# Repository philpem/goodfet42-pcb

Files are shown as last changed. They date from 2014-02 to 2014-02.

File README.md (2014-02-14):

GoodFET42 Modified PCB

This is a modified version of Travis Goodspeed's "GoodFET42" JTAG pod design.
The schematic has not been modified (except for renaming "LED1" to "MO" to
indicate its role as the Mode LED), but the PCB has been modified to allow it to
be built by hobbyists with a relatively modest home PCB lab.

Design rules are thus:

  * Top and bottom sides are linked by large vias, well away from ICs. This
    allows the top and bottom sides to be linked with Harwin track pins, pieces
    of solid-core wire, or similar things.
  * Tracks may enter SMD pads from the short side only, perpendicular with the
    long side (in other words: "make the pad longer"). This makes it easier to
    determine whether a short between two IC pins is intentional.
  * IDC connector is soldered on the bottom side only; tracks may connect from
    the bottom layer only. Most home PCB labs don't have through-plating
    facilities :)
  * 16 mil isolation from ground plane to tracks and pads.

Enjoy!

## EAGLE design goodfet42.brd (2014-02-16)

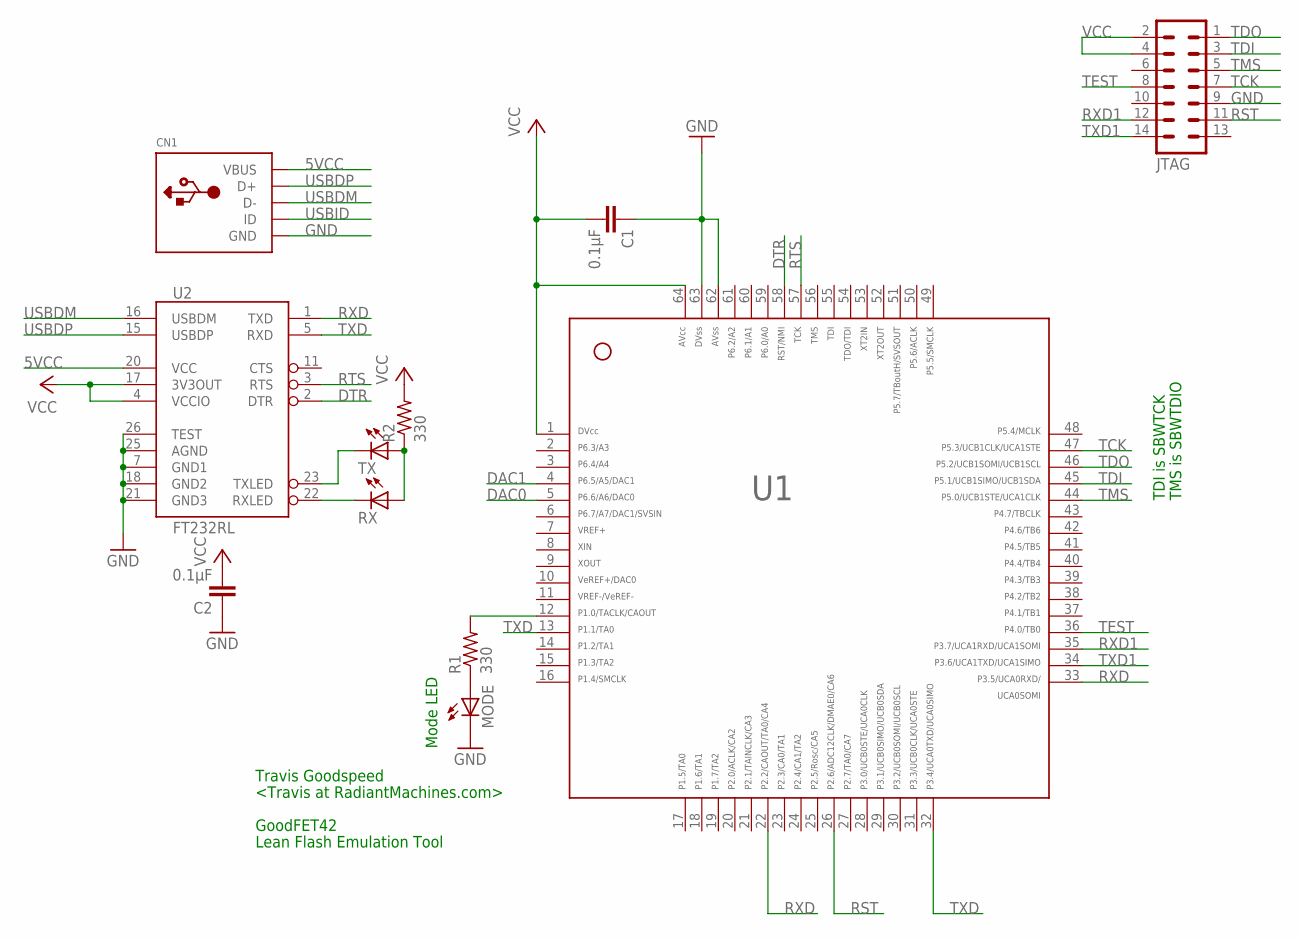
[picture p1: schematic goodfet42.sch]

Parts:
C1, C2: 0.1µF; C0603
CN1: USBMINIB; USB-MINIB
JTAG: MA07-2
MODE: LEDCHIP-LED0603; CHIP-LED0603
R1, R2: 330; R0603
RX: LEDCHIP-LED0603; CHIP-LED0603
TX: LEDCHIP-LED0603; CHIP-LED0603
U1: MSP430F2618TPM; PM/PAG64
U2: FT232RL; SSOP28DB

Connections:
5VCC: CN1.VBUS, U2.20 (VCC)
DAC0: U1.5
DAC1: U1.4
DTR: U1.58, U2.2 (DTR)
GND: C1.1, C2.1, CN1.GND, JTAG.9, MODE.C, U1.62, U1.63, U2.7 (GND1), U2.18 (GND2), U2.21 (GND3), U2.25 (AGND), U2.26 (TEST)
unnamed: R1.2, U1.12
unnamed: MODE.A, R1.1
unnamed: RX.C, U2.22 (RXLED)
unnamed: TX.C, U2.23 (TXLED)
unnamed: R2.1, RX.A, TX.A
RST: JTAG.11, U1.26
RTS: U1.57, U2.3 (RTS)
RXD: U1.22, U1.33, U2.1 (TXD)
RXD1: JTAG.12, U1.35
TCK: JTAG.7, U1.47
TDI: JTAG.3, U1.45
TDO: JTAG.1, U1.46
TEST: JTAG.8, U1.36
TMS: JTAG.5, U1.44
TXD: U1.13, U1.32, U2.5 (RXD)
TXD1: JTAG.14, U1.34
USBDM: CN1.D-, U2.16 (USBDM)
USBDP: CN1.D+, U2.15 (USBDP)
USBID: CN1.ID
VCC: C1.2, C2.2, JTAG.2, JTAG.4, R2.2, U1.1, U1.64, U2.4 (VCCIO), U2.17 (3V3OUT)

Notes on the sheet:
TDI is SBWTCK
TMS is SBWTDIO
Mode LED
Travis Goodspeed
<Travis at RadiantMachines.com>
GoodFET42
Lean Flash Emulation Tool

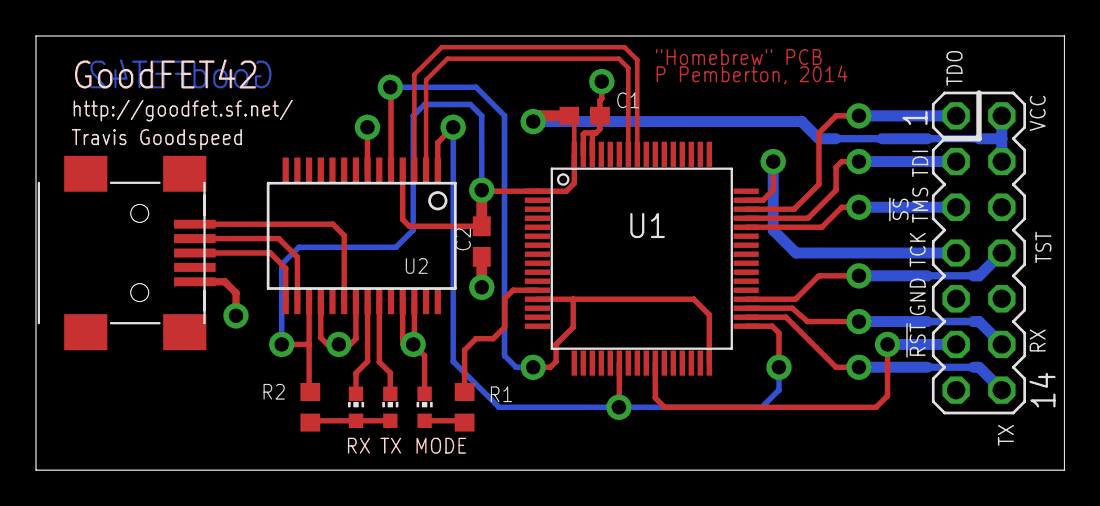
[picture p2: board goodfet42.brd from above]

Board: 2 copper layers, 57.1 x 24.1 mm, 11 parts (0 on the bottom side), 22 nets.

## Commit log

2014-02-14 Commit modified GoodFET42 board, tweaked for home etching
    [goodfet42.brd, goodfet42.sch]
2014-02-15 rename MO LED to MODE, silkscreen fixes, add Homebrew PCB designation
    [goodfet42.brd, goodfet42.sch]
2014-02-16 add 'GoodFET42' text on bottom layer to help with board alignment
    [goodfet42.brd]
